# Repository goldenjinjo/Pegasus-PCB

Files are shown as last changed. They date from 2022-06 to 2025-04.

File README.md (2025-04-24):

Schematic And PCB Design for Pegasus Flight Computer in Kicad. 
Designed to track 3D position via GPS and transmit to ground station.
Originally developed for the UNSW Rocketry Team.

**PARTS LIST:**

- Microprocessor: Teensy 4
- GPS: Quectel L70B-M39
- Radio Transceiver: RFD900ux
- Memory: XTSD 4GB NAND Flash
- RGB LED

---
## 📸 Overview

### 📐 PCB Layout

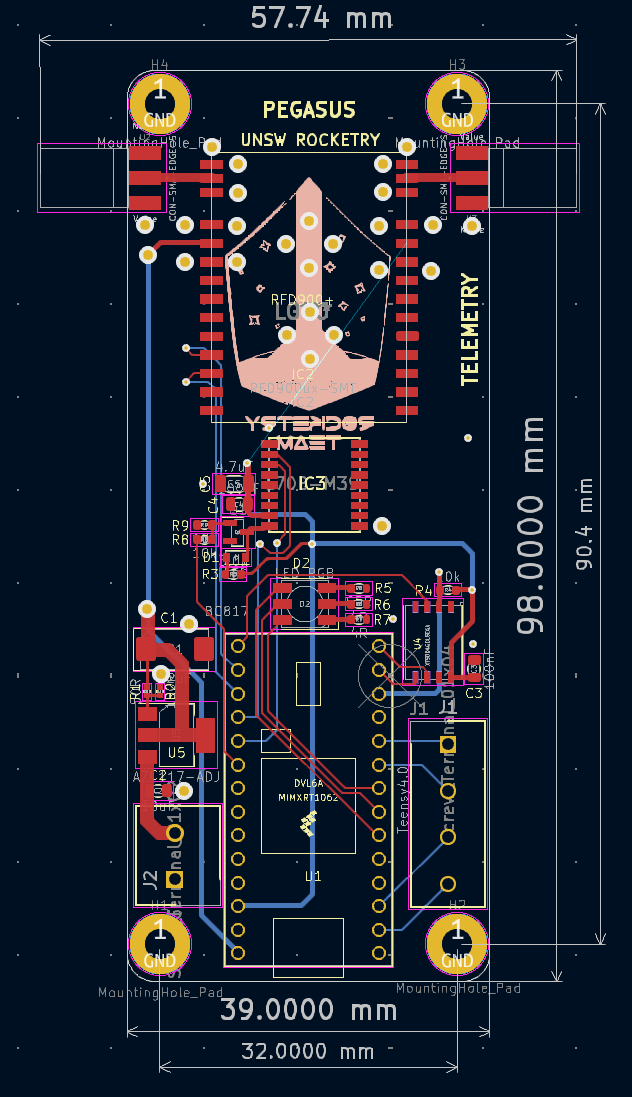
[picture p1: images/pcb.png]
PCB Layout


**Dimensions**: 
- 98.0 mm × 39 mm board length
- 98.0mm x 57.74 mm maximum horizontal (due to antennas)
  
**Mounting Holes**: ⌀3.2 mm (4-cornered)

---
## 📊 Schematic

Schematic

---

### ⚙️ Render – Front Side

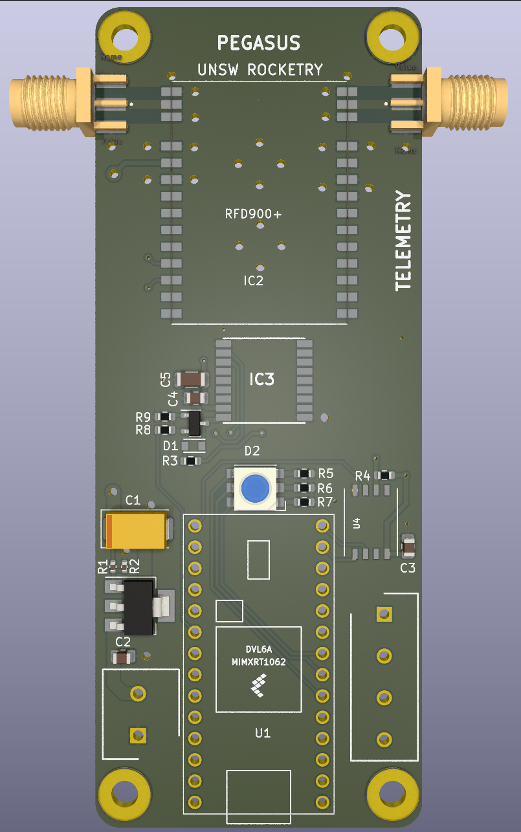
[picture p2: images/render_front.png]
Front Render


---

### 🔧 Render – Back Side

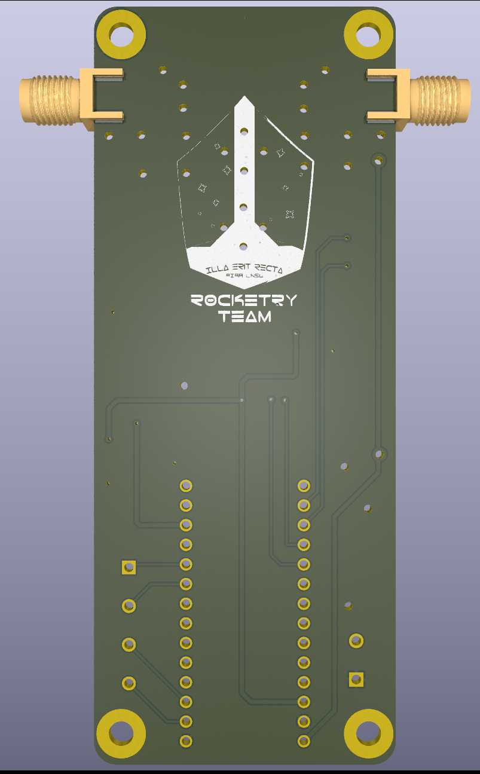
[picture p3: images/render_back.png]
Back Render


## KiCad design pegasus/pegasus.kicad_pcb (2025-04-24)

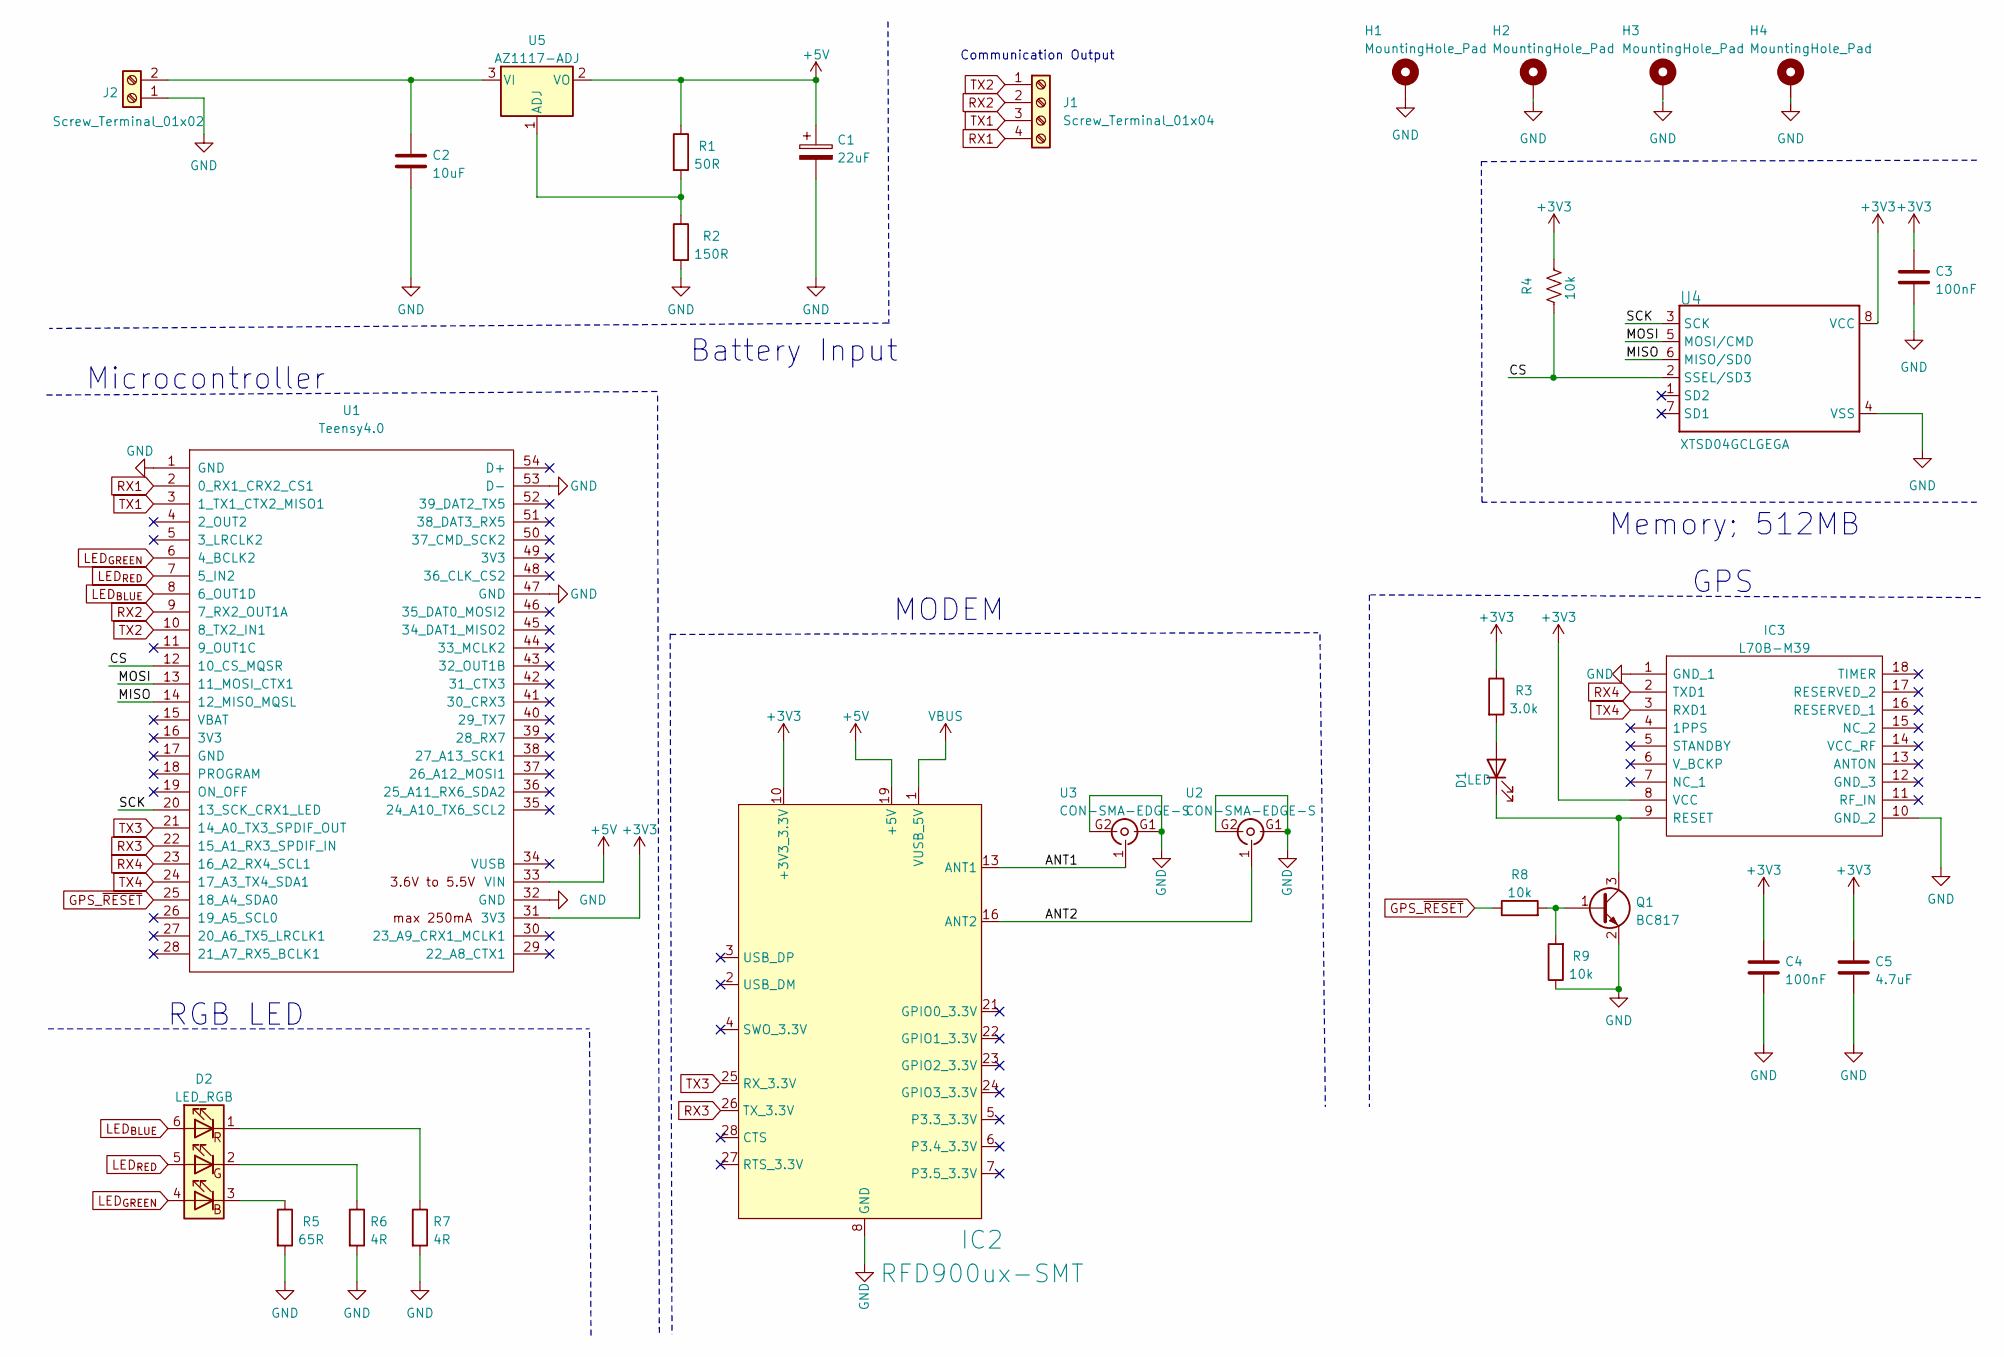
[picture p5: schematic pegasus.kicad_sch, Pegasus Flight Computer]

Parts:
C1: 22uF; CP_EIA-7343-30_AVX-N
C2: 10uF; C_0805_2012Metric
C3, C4: 100nF; C_0805_2012Metric
C5: 4.7uF; C_1206_3216Metric
D1: LED; LED_miniPLCC_2315
D2: LED_RGB; LED_RGB_5050-6
H1, H2, H3, H4: MountingHole_Pad; MountingHole_3.2mm_M3_Pad
IC2: RFD900ux-SMT; 1x28
IC3: L70B-M39; 1x18; Manufacturer_Part_Number L70B-M39; Mouser Part Number 277-L70B-M39
J1: Screw_Terminal_01x04; SHDR4W100P0X500_1X4_2000X800X1000P
J2: Screw_Terminal_01x02; SHDR2W105P0X500_1X2_1060X900X1250P
Q1: BC817; SOT-23
R1: 50R; C_0402_1005Metric
R2: 150R; C_0402_1005Metric
R3: 3.0k; R_0603_1608Metric
R4: 10k; R_0603_1608Metric; LCSC C332266
R5: 65R; R_0603_1608Metric
R6, R7: 4R; R_0603_1608Metric
R8, R9: 10k; R_0603_1608Metric
U1: Teensy4.0; Teensy40
U2, U3: CON-SMA-EDGE-S; RFSOLUTIONS_CON-SMA-EDGE-S
U4: XTSD04GCLGEGA; LGA8_8X6; LCSC C2759953
U5: AZ1117-ADJ; SOT-223-3_TabPin2

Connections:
+3V3: C3.1, C4.1, C5.1, IC2.10 (+3V3_3.3V), IC3.8 (VCC), R3.1, R4.1, U1.31 (3V3), U4.8 (VCC)
+5V: C1.1, IC2.19 (+5V), R1.1, U1.33 (VIN), U5.2 (VO)
/ANT1: IC2.13 (ANT1), U3.1
/ANT2: IC2.16 (ANT2), U2.1
/CS: R4.2, U1.12 (10_CS_MQSR), U4.2 (SSEL/SD3)
/MISO: U1.14 (12_MISO_MQSL), U4.6 (MISO/SD0)
/MOSI: U1.13 (11_MOSI_CTX1), U4.5 (MOSI/CMD)
/SCK: U1.20 (13_SCK_CRX1_LED), U4.3 (SCK)
GND: C1.2, C2.2, C3.2, C4.2, C5.2, H1.1, H2.1, H3.1, H4.1, IC2.8 (GND), IC2.9 (GND), IC2.11 (GND), IC2.12 (GND), IC2.14 (GND), IC2.15 (GND), IC2.17 (GND), IC2.18 (GND), IC2.20 (GND), IC3.1 (GND_1), IC3.10 (GND_2), J2.1, Q1.2 (E), R2.2, R5.2, R6.2, R7.2, R9.1, U1.1 (GND), U1.32 (GND), U1.47 (GND), U1.53 (D-), U2.G1, U2.G2, U3.G1, U3.G2, U4.4 (VSS)
GPS_~RESET: R8.1, U1.25 (18_A4_SDA0)
LED_{BLUE}: D2.4 (BA), U1.6 (4_BCLK2)
LED_{GREEN: D2.5 (GA), U1.7 (5_IN2)
LED_{RED}: D2.6 (RA), U1.8 (6_OUT1D)
unnamed: C2.1, J2.2, U5.3 (VI)
unnamed: D1.1 (K), IC3.9 (RESET), Q1.3 (C)
unnamed: D1.2 (A), R3.2
unnamed: D2.1 (RK), R7.1
unnamed: D2.2 (GK), R6.1
unnamed: D2.3 (BK), R5.1
unnamed: Q1.1 (B), R8.2, R9.2
unnamed: R1.2, R2.1, U5.1 (ADJ)
RX1: J1.4, U1.2 (0_RX1_CRX2_CS1)
RX2: J1.2, U1.9 (7_RX2_OUT1A)
RX3: IC2.26 (TX_3.3V), U1.22 (15_A1_RX3_SPDIF_IN)
RX4: IC3.2 (TXD1), U1.23 (16_A2_RX4_SCL1)
TX1: J1.3, U1.3 (1_TX1_CTX2_MISO1)
TX2: J1.1, U1.10 (8_TX2_IN1)
TX3: IC2.25 (RX_3.3V), U1.21 (14_A0_TX3_SPDIF_OUT)
TX4: IC3.3 (RXD1), U1.24 (17_A3_TX4_SDA1)
VBUS: IC2.1 (VUSB_5V)

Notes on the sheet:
Battery Input
Communication Output
GPS
Memory; 512MB
Microcontroller
MODEM
RGB LED

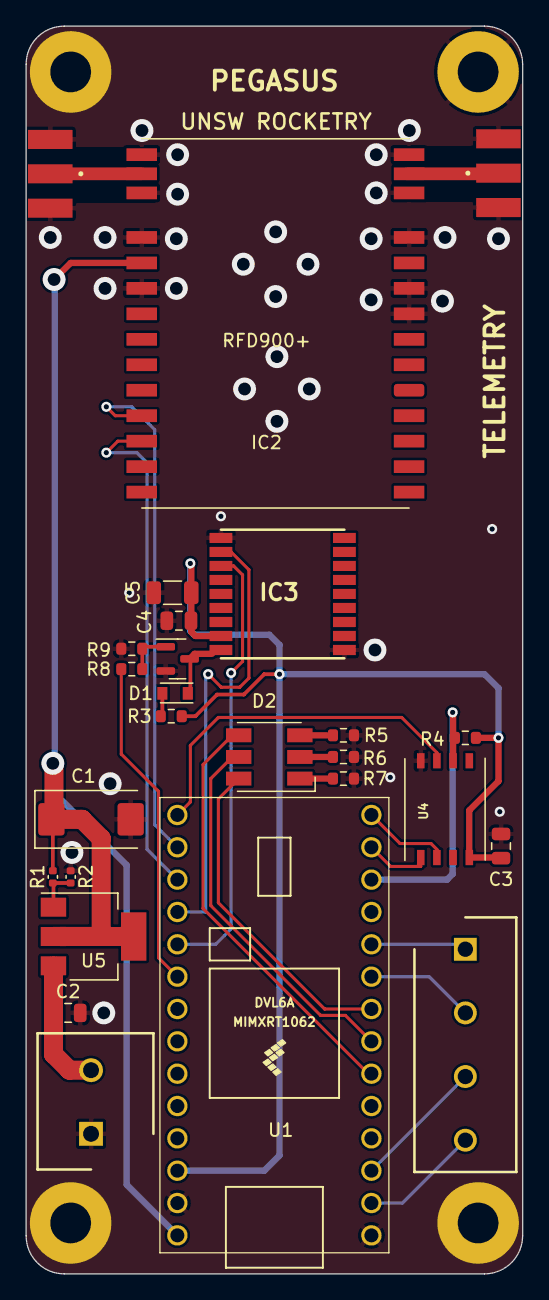
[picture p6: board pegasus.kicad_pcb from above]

Board: 2 copper layers, 39.0 x 98.0 mm, 30 parts (0 on the bottom side), 29 nets.

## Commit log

2022-06-28 import pegasus project file from hardware repo, add readme and .gitignore
    [pegasus.kicad_pcb, pegasus.kicad_sch]
2022-06-30 replace teensy 4.1 wih teensy 4, remove barometer and IMU
    [pegasus.kicad_pcb, pegasus.kicad_sch]
2022-06-30 replace sma-connectors with screw terminal with switch
    [pegasus.kicad_pcb, pegasus.kicad_sch]
2022-06-30 add external RX TX connectors
    [pegasus.kicad_pcb, pegasus.kicad_sch]
2022-06-30 add rgb led
    [pegasus.kicad_pcb, pegasus.kicad_sch]
2022-07-21 change mount holes to m3, draft new component layout, reduce size to 39x105mm
    [pegasus.kicad_pcb, pegasus.kicad_sch]
2022-07-21 add second rx-tx screw terminal connector, optimize pin assignment for other components
    [pegasus.kicad_pcb, pegasus.kicad_sch]
2022-07-21 add xtsd footprint library, and xtsd nand chip to pcb
    [pegasus.kicad_pcb, pegasus.kicad_sch]
2022-07-21 re add ground plane
    [pegasus.kicad_pcb]
2022-07-26 add borders and titles to components in schematic
    [pegasus.kicad_pcb, pegasus.kicad_sch]
2022-07-27 add some traces
    [pegasus.kicad_pcb]
2022-07-27 New voltage regulator added to schematic and pcb
    [pegasus.kicad_pcb, pegasus.kicad_sch]
2022-07-28 add vias to top through holes, change antenna to route to common ground
    [pegasus.kicad_sch]
2022-07-28 Route LED and memory on PCB
    [pegasus.kicad_pcb, pegasus.kicad_sch]
2022-08-10 Voltage regulator fixes
    [pegasus.kicad_pcb]
2022-08-10 increasing spacing of components, route rx-tx of gps
    [pegasus.kicad_pcb]
2022-08-10 route GND and 3.3V traces
    [pegasus.kicad_sch]
2022-08-10 move rfd900 closer to gps, decrease length to 98mm
    [pegasus.kicad_pcb]
2022-08-11 route all traces to rfd900
    [pegasus.kicad_pcb]
2022-08-11 add via stitching and more spacing between traces
    [pegasus.kicad_pcb]
2022-08-11 add missing round pin to rfd900
    [pegasus.kicad_pcb, pegasus.kicad_sch]
2022-08-11 remove unused teensy 4 pins from footprint
    [pegasus.kicad_pcb]
2022-09-23 replace voltage regulator with 1A capable, variable regulator. Increase via size for PCB mill prototyping. Add more vias for RFD900
    [pegasus.kicad_pcb, pegasus.kicad_sch]
2022-09-23 add headings to and general clean up to schematic
    [pegasus.kicad_sch]
2022-09-23 reposition GPS to center of board, add gps reset circuitry
    [pegasus.kicad_pcb, pegasus.kicad_sch]
2022-10-01 change LED pin names to reflect proper colors
    [pegasus.kicad_sch]
2023-10-16 clean silkscreen
    [pegasus.kicad_pcb]
2025-04-24 move logo into component libraries
    [pegasus.kicad_pcb]
2025-04-24 remove depreacted libraries
    [pegasus.kicad_sch]
2025-04-24 remove unneccessary GPS footprint info, clean up fabs
    [pegasus.kicad_pcb]
2025-04-24 add dimensions to PCB
    [pegasus.kicad_pcb]
